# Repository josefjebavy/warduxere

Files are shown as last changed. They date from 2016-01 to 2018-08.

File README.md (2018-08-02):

Warduxere
===========================================
Wireless Arduino with low power consumption

Warduxere (old name was Warduino) was awarded the prize in a magazine for the design of electronic journals [PE-AR](http://www.aradio.cz/). 
### About ###
This project is open-source alternative for other proprietary platform.

It is base on Arduino - CPU AVR ATmega328.
This device is designed for wireless comunication and long run on battery.

### Using 
directories contain
- arduino - example program for arduino - wiring language
- pcb - scheme in Kicad and pcb

## Scheme
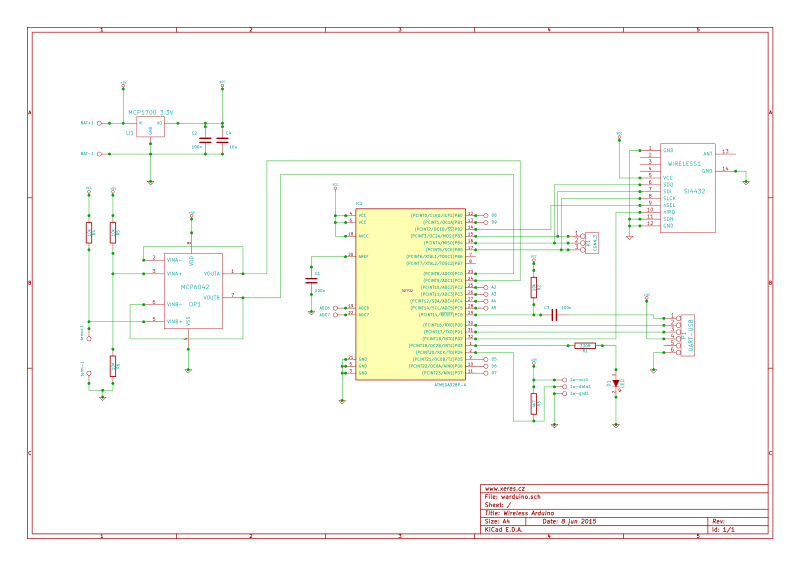
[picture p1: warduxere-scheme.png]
Scheme


## 3D view of device
First model from year 2014.

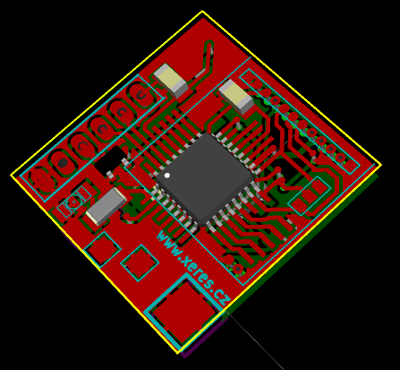
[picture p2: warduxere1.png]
3D view top


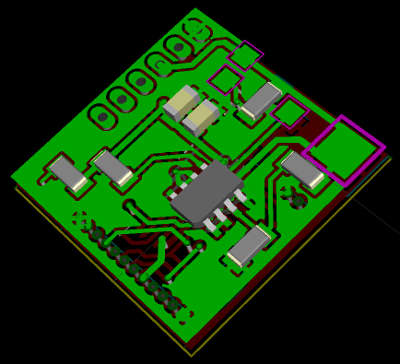
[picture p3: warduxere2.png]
3D view bottom


warduxere DPS v2
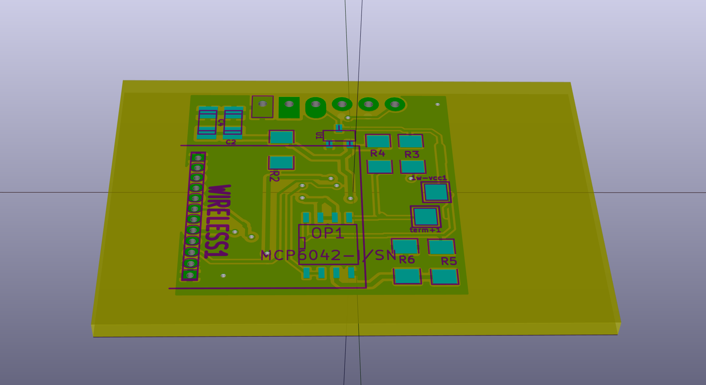
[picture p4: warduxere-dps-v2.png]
3D view warduxere DPS v2


[warduxere documentation](https://blog.josefjebavy.cz/warduxere)

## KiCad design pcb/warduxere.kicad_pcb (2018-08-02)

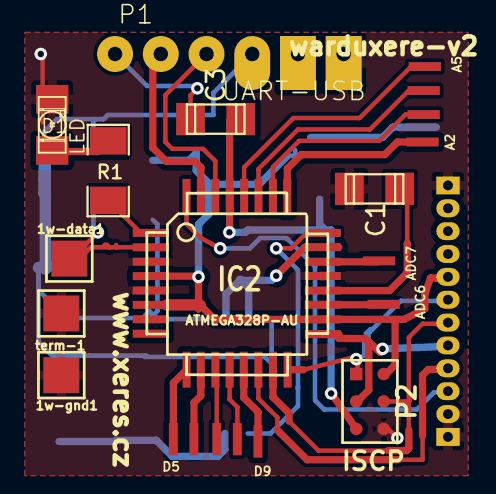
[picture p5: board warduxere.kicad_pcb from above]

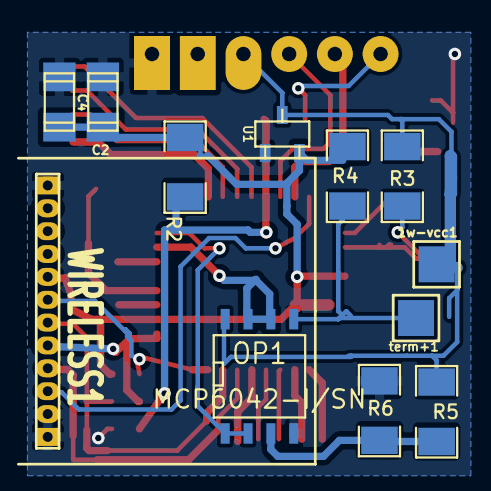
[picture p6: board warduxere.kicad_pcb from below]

Board: 2 copper layers, 33 parts (12 on the bottom side), 31 nets.

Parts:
1w-data1, 1w-gnd1, 1w-vcc1: CONN_1; 1PIN_SMDx
A2, A3, A4, A5: CONN_1; 1PIN_SMDxx
ADC6, ADC7: CONN_1; 1PIN_SMDxx
C1, C2, C3: 100n; c_1206
C4: 10u; c_1206
D1: LED; LED-1206
D5, D6, D7, D8, D9: CONN_1; 1PIN_SMDxx
IC2: ATMEGA328P-AU; TQFP32
OP1: MCP6042-I/SN; SO8N
P1: UART-USB; PINHEAD1-6x+
P2: ISCP; pin_array_3x2X-ISCP
R1: 330R; SM1206
R2, R4: 10K; SM1206
R3: 4K7; SM1206
R5, R6: 1M; SM1206
U1: MCP1700T-3302E/TT; sot23
WIRELESS1: SI4432; si4432
term+1: CONN_1; 1PIN_SMDx
term-1: CONN_1; 1PIN_SMDx

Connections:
+3.3V: C2.1, C4.1, IC2.4, IC2.6, IC2.18, P2.2, R2.1, R4.1, U1.3, WIRELESS1.5
+5V: 1w-vcc1.1, OP1.8, P1.4, R3.1, R5.1, U1.2
GND: 1w-gnd1.1, C1.2, C2.2, C4.2, D1.2, IC2.3, IC2.5, IC2.21, OP1.4, P1.6, P2.6, R6.2, U1.1, WIRELESS1.1, WIRELESS1.11, WIRELESS1.12, term-1.1
unnamed: IC2.24, OP1.1, OP1.2
unnamed: IC2.32, WIRELESS1.10
unnamed: IC2.23, OP1.6, OP1.7
unnamed: OP1.5, R4.2, term+1.1
unnamed: OP1.3, R5.2, R6.1
unnamed: IC2.17, P2.3, WIRELESS1.8
unnamed: C3.2, IC2.29, P2.5, R2.2
unnamed: IC2.14, WIRELESS1.9
unnamed: IC2.15, P2.4, WIRELESS1.7
unnamed: D1.1, R1.1
unnamed: IC2.16, P2.1, WIRELESS1.6
unnamed: C1.1, IC2.20
unnamed: 1w-data1.1, IC2.2, R3.2
unnamed: IC2.31, P1.2
unnamed: ADC6.1, IC2.19
unnamed: A5.1, IC2.28
unnamed: A4.1, IC2.27
unnamed: C3.1, P1.1
unnamed: IC2.1, R1.2
unnamed: D8.1, IC2.12
unnamed: A3.1, IC2.26
unnamed: A2.1, IC2.25
unnamed: D9.1, IC2.13
unnamed: ADC7.1, IC2.22
unnamed: D7.1, IC2.11
unnamed: IC2.30, P1.3
unnamed: D6.1, IC2.10
unnamed: D5.1, IC2.9

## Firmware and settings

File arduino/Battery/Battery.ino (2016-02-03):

/*
  Warduxere - Battery
 
 Get battery status 
 This example code is in the public domain.
 
 Author: Bc. Josef Jebavý
 web: http://www.xeres.cz
 about project: http://multi.xeres.cz/programovani/wireless-arduino-low-power-consumption
 
 
 */

#define PINBAT A1
// the setup routine runs once when you press reset:
void setup() {

  Serial.begin(9600);

  pinMode(PINBAT, INPUT);


}

// the loop routine runs over and over again forever:
void loop() {


  //mereni baterie
  int sensorValue=analogRead(PINBAT);
  byte bat=0;

  // na LDO je ubitek napeti 0.178V takze pod 3.478V na baterii uz procesor a ADC bude napajen mene jak 3.3V
  // pro 3.3V arduino a delic 1:1 bude cislo odpovidat napeti na baterii:
  // 528 - 3.40V
  // 539 - 3.478V - hranice pro spravne napajeni
  // 550 - 3.544
  // 559 - 3.60V - hranice pro li-pol/ion baterii

  if (  sensorValue>558) {  
    bat=1;  
  }



  Serial.print("battery:");
  Serial.print(bat);
  Serial.print(";value:");
  Serial.print(sensorValue);
  Serial.print(";V:");
  double d =3.3/1024*sensorValue*2;
  Serial.print(d,4);
  Serial.println();

  delay(1000);  
}

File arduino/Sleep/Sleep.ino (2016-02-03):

/*
 Warduxere - Sleep
 Example of sleeping and saving power
 
 This example code is in the public domain.
 
 Author: Bc. Josef Jebavý
 web: http://www.xeres.cz
 about project: http://www.multi.xeres.cz/programovani/wireless-arduino-low-power-consumption
 
 
 */



#include <avr/sleep.h>
#include <avr/wdt.h>
#include <SPI.h>
#include <RH_RF22.h>

// Singleton instance of the radio driver
RH_RF22 rf22;
#define LED 3

// watchdog interrupt
ISR(WDT_vect) 
{
  wdt_disable();  // disable watchdog
}

void myWatchdogEnable(const byte interval) 
{  

  // turn off brown-out enable in software
  MCUCR = bit (BODS) | bit (BODSE);
  MCUCR = bit (BODS); 

  int previousADCSRA = ADCSRA;    
  ADCSRA &= ~(1<<ADEN); //Disable ADC
  ACSR = (1<<ACD); //Disable the analog comparator
  DIDR0 = 0x3F; //Disable digital input buffers on all ADC0-ADC5 pins
  DIDR1 = (1<<AIN1D)|(1<<AIN0D); //Disable digital input buffer on AIN1/0


  //toto nejde zkompilovat pro atmega8
  MCUSR = 0;                          // reset various flags
  WDTCSR |= 0b00011000;               // see docs, set WDCE, WDE
  WDTCSR =  0b01000000 | interval;    // set WDIE, and appropriate delay

  wdt_reset();
  set_sleep_mode (SLEEP_MODE_PWR_DOWN);  
  sleep_mode();            // now goes to Sleep and waits for the interrupt

  //zapnuti ADC
  ADCSRA = previousADCSRA;
} 

void setup()
{


  pinMode (LED, OUTPUT);

  PRR = bit(PRTIM1);                           // only keep timer 0 going
  // ADCSRA &= ~ bit(ADEN); 
  // bitSet(PRR, PRADC); 
  rf22.init();
}  


void loop()
{


  // awake
  digitalWrite (LED, HIGH);  
  delay (4000);

  //not sleeping not lihgt
  digitalWrite (LED, LOW); 
  delay (4000); 


   //blink before sleep
  digitalWrite (LED, HIGH);  
  delay (200);
  digitalWrite (LED, LOW); 

  //sleep wireless module
  rf22.sleep();
  // sleep 8 seconds
  myWatchdogEnable (0b100001);  
  // sleep bit patterns:
  //  1 second:  0b000110
  //  2 seconds: 0b000111
  //  4 seconds: 0b100000
  //  8 seconds: 0b100001

}  

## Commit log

2016-01-09 add Kicad project: scheme,PCB,...
    [warduino-append.kicad_pcb, warduino.kicad_pcb, warduino.sch]
2016-02-07 rename pcb files
    [warduxere-append.kicad_pcb, warduxere.kicad_pcb, warduxere.sch]
2018-08-02 DPS version2
    [warduxere.kicad_pcb]
